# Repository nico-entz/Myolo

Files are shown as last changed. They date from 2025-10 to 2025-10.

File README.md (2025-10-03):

# Myolo

Myolo ist ein Partikel/Myonendetektor auf der Basis von Szintillatoren und Silizium-Photodioden, der ohne SMD-Bauteile aufgebaut werden kann.

Myolo nutzt Koinzidenz, um Myonen von anderen Teilchen zu unterscheiden. Um dies zu realisieren, nutzt er zwei voneinander unabhängige Detektoren. Anhand der zeitlichen Korrelation der Signale beider Detektoren kann auf die Teilchenart geschlossen werden.

Als Szintillatoren kommen Bicron BC408-Plastikszintillatoren der Maße 50x50x10 mm zum Einsatz.

Als SiPMs werden onsemi MICROFC-60035-SMT-TR genutzt. Die Bias-Spannung von 29,5 V wird mittels eines simplen DC-DC-Wandlers erzeugt.

Die für die Operationsverstärkerschaltung notwendige symmetrische Versorgungsspannung von +/- 15V wird ebenfalls durch einen DC-DC-Wandler erzeugt.

Myolo basiert lose auf dem CosmicWatch-Projekt (http://www.cosmicwatch.lns.mit.edu/) und nutzt daher auch dessen SiPM-PCB (https://github.com/spenceraxani/CosmicWatch-Desktop-Muon-Detector-v2/blob/master/PCB_Files/PCB_Gerber_files.zip).

Im Gegensatz zu CosmicWatch nutzt Myolo jedoch einen leistungsfähigen STM32H7-Mikrocontroller, wodurch es möglich wird, beide Detektoren quasi zeitgleich auszulesen.

--------------------------------------

Myolo is a particle/muon detector based on scintillators and silicon photodiodes that can be constructed without SMD components.

Myolo uses the coincidence method to distinguish muons from other particles. To achieve this, it uses two independent detectors. The type of particle can be determined based on the temporal correlation of the signals from both detectors.

Bicron BC408 plastic scintillators measuring 50x50x10 mm are used as scintillators.

Onsemi MICROFC-60035-SMT-TR are used as SiPMs. The bias voltage of 29.5 V is generated by a simple DC-DC converter. 

The symmetrical supply voltage of +/- 15V required for the operational amplifier circuit is also generated by a DC-DC converter.

Myolo is loosely based on the CosmicWatch project (http://www.cosmicwatch.lns.mit.edu/) and therefore also uses its SiPM PCB (https://github.com/spenceraxani/CosmicWatch-Desktop-Muon-Detector-v2/blob/master/PCB_Files/PCB_Gerber_files.zip).

Unlike CosmicWatch, however, Myolo uses a powerful STM32H7 microcontroller, which makes it possible to read out both detectors virtually simultaneously.

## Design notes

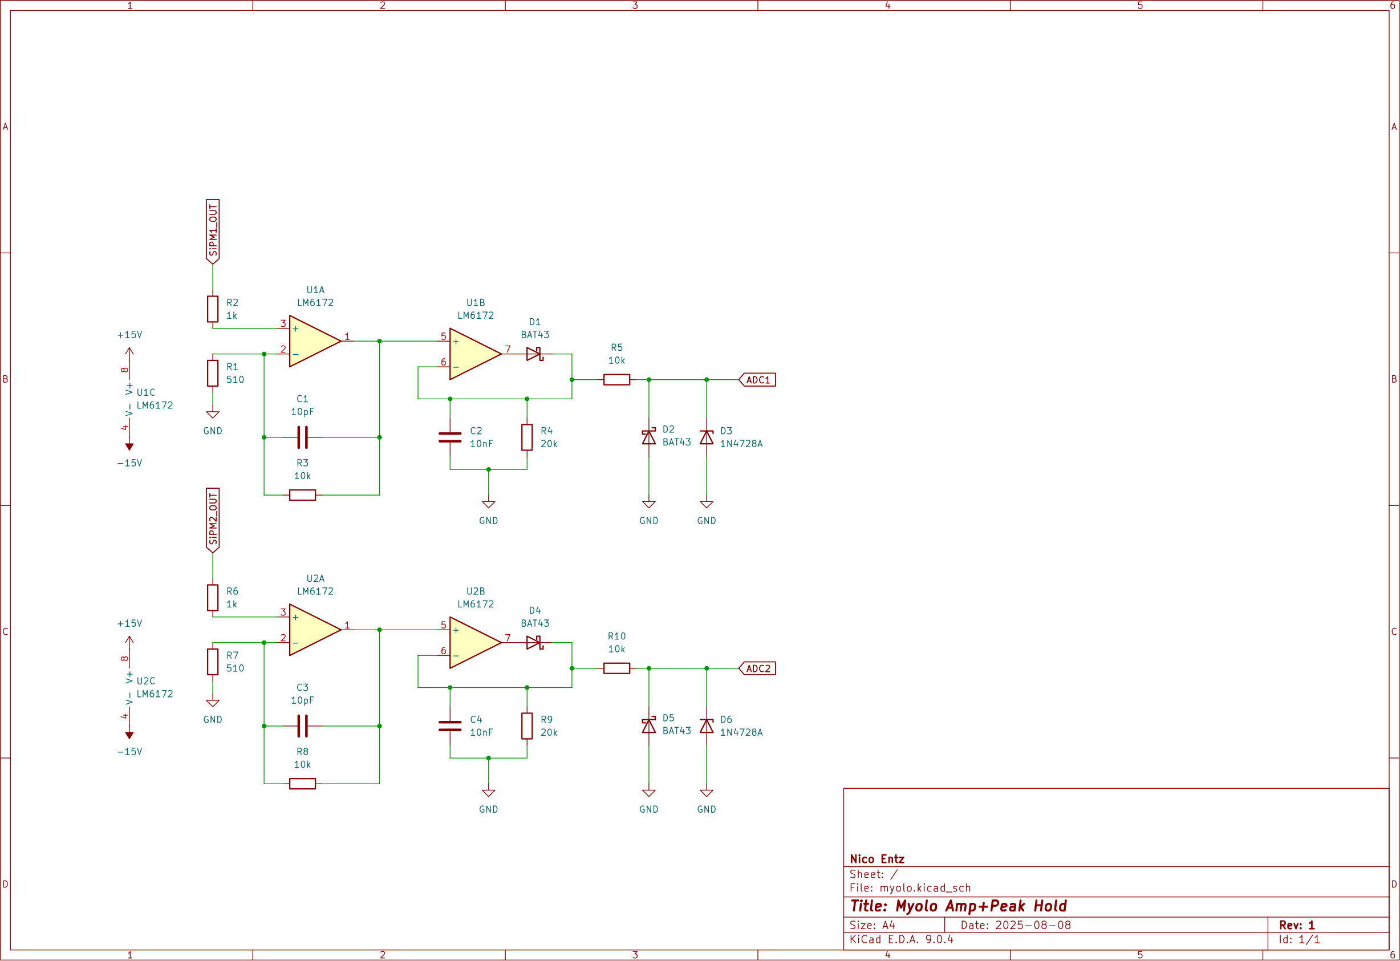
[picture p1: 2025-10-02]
circuit_diagrams/circuit_diagram.png

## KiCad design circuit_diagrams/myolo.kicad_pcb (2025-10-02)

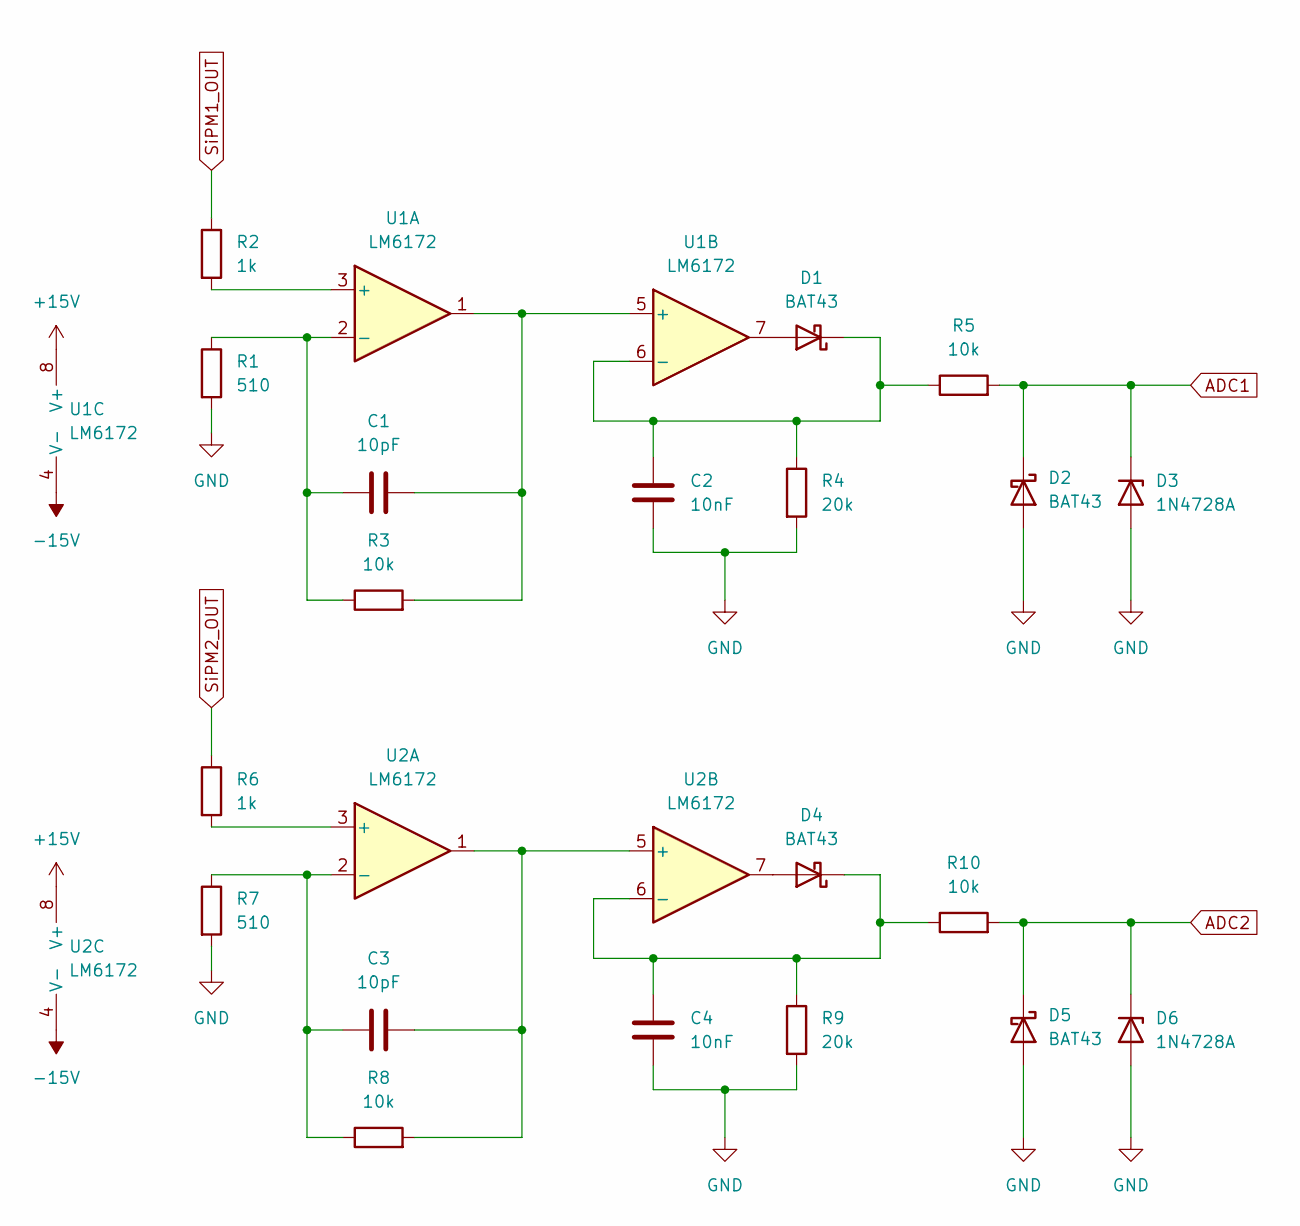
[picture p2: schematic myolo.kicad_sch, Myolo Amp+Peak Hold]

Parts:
C1, C3: 10pF; CP_Radial_D4.0mm_P2.00mm
C2, C4: 10nF; CP_Radial_D4.0mm_P2.00mm
D1, D2, D4, D5: BAT43; D_DO-35_SOD27_P7.62mm_Horizontal
D3, D6: 1N4728A; D_DO-41_SOD81_P10.16mm_Horizontal
R1, R7: 510; R_Axial_DIN0207_L6.3mm_D2.5mm_P15.24mm_Horizontal
R2, R6: 1k; R_Axial_DIN0207_L6.3mm_D2.5mm_P15.24mm_Horizontal
R3, R5, R8, R10: 10k; R_Axial_DIN0207_L6.3mm_D2.5mm_P15.24mm_Horizontal
R4, R9: 20k; R_Axial_DIN0207_L6.3mm_D2.5mm_P15.24mm_Horizontal
U1, U2: LM6172; DIP-8_W10.16mm

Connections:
+15V: U1.8 (V+), U2.8 (V+)
-15V: U1.4 (V-), U2.4 (V-)
ADC1: D2.1 (K), D3.1 (K), R5.2
ADC2: D5.1 (K), D6.1 (K), R10.2
GND: C2.2, C4.2, D2.2 (A), D3.2 (A), D5.2 (A), D6.2 (A), R1.2, R4.2, R7.2, R9.2
unnamed: D1.2 (A), U1.7
unnamed: C2.1, D1.1 (K), R4.1, R5.1, U1.6 (-)
unnamed: D4.2 (A), U2.7
unnamed: C4.1, D4.1 (K), R9.1, R10.1, U2.6 (-)
unnamed: R2.2, U1.3 (+)
unnamed: C1.1, R1.1, R3.1, U1.2 (-)
unnamed: C1.2, R3.2, U1.1, U1.5 (+)
unnamed: R6.2, U2.3 (+)
unnamed: C3.1, R7.1, R8.1, U2.2 (-)
unnamed: C3.2, R8.2, U2.1, U2.5 (+)
SiPM1_OUT: R2.1
SiPM2_OUT: R6.1

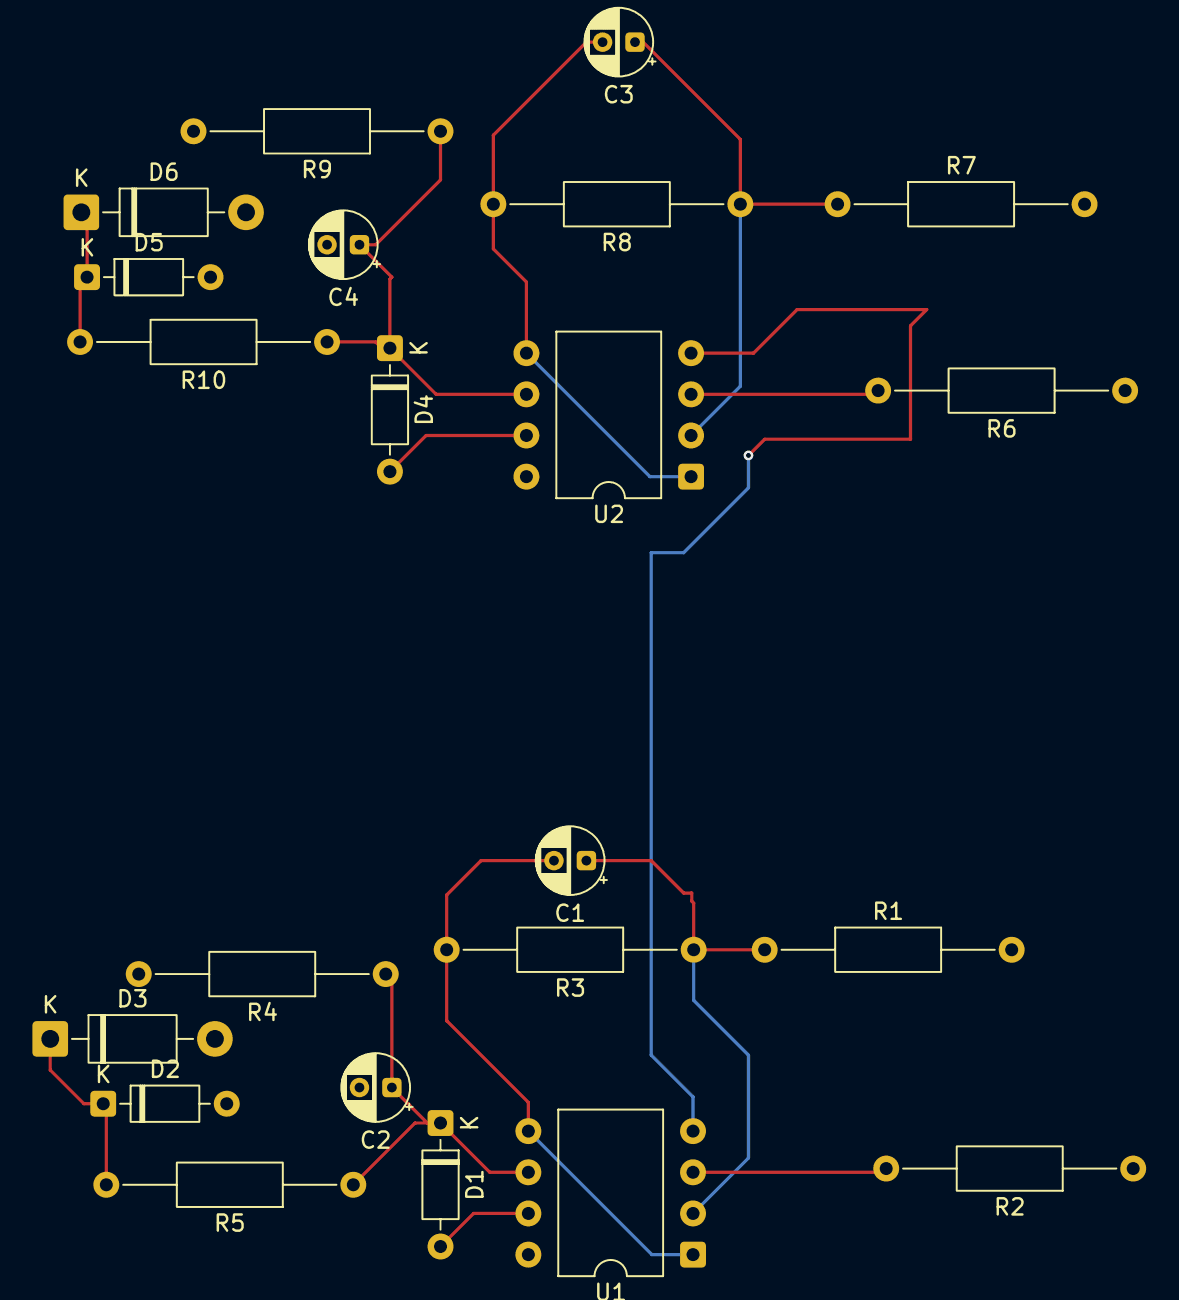
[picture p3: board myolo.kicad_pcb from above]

Board: 2 copper layers, 22 parts (0 on the bottom side), 15 nets.

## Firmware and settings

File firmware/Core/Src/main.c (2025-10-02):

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
/* Includes ------------------------------------------------------------------*/
#include "main.h"
#include "fatfs.h"
#include "usb_device.h"

/* USER CODE BEGIN Includes */
#include <string.h>
#include <st7735.h>
#include "fonts.h"
#include "testimg.h"
#include <math.h>

/* USER CODE END Includes */

ADC_HandleTypeDef hadc1;
ADC_HandleTypeDef hadc2;

SD_HandleTypeDef hsd1;

SPI_HandleTypeDef hspi4;

TIM_HandleTypeDef htim2;

UART_HandleTypeDef huart2;

/* USER CODE BEGIN PV */
long counter = 0;
bool written = false;
volatile long adc_callback_counter = 0;
#define ADCBUFSIZE 1000
uint32_t adcbuf[ADCBUFSIZE];
bool adc_ready = false;

char log_filename[32];
uint32_t file_counter = 0;

/* USER CODE END PV */

void SystemClock_Config(void);
void PeriphCommonClock_Config(void);
static void MPU_Config(void);
static void MX_GPIO_Init(void);
static void MX_SPI4_Init(void);
static void MX_ADC1_Init(void);
static void MX_ADC2_Init(void);
static void MX_TIM2_Init(void);
static void MX_SDMMC1_SD_Init(void);
static void MX_USART2_UART_Init(void);
/**
  * @brief  The application entry point.
  * @retval int
  */
int main(void)
{

  /* MPU Configuration--------------------------------------------------------*/
  MPU_Config();

  /* MCU Configuration--------------------------------------------------------*/

  /* Reset of all peripherals, Initializes the Flash interface and the Systick. */
  HAL_Init();

  /* Configure the system clock */
  SystemClock_Config();

  /* Configure the peripherals common clocks */
  PeriphCommonClock_Config();

  /* Initialize all configured peripherals */
  MX_GPIO_Init();
  MX_SPI4_Init();
  MX_ADC1_Init();
  MX_ADC2_Init();
  MX_TIM2_Init();
  MX_USB_DEVICE_Init();
  MX_SDMMC1_SD_Init();
  MX_FATFS_Init();
  MX_USART2_UART_Init();
  /* USER CODE BEGIN 2 */

  // init display
  ST7735_Init();

  // clear display
  ST7735_FillScreen(0x0000);

  // adc calibration
  HAL_ADCEx_Calibration_Start(&hadc1, ADC_SINGLE_ENDED, DISABLE);
  HAL_ADCEx_Calibration_Start(&hadc2, ADC_SINGLE_ENDED, DISABLE);

  // start timer
  HAL_TIM_Base_Start_IT(&htim2);
  /* USER CODE END 2 */

  /* Infinite loop */
  /* USER CODE BEGIN WHILE */

  // definitions for upper and lower threshold
  // (detector is triggered if ADC value hits upper threshold)
  // (all values are buffered until ADC value hits lower threshold)
  // (then the mean value of these values is calculated)
  uint16_t upper_thresh = 400;
  uint16_t lower_thresh = 300;

  // define allowed coincidence time difference
  uint16_t coincidence_window = 100;

  bool triggered = false;
  bool triggered2 = false;

  uint32_t sumval = 0;
  uint32_t conv_cnt = 0;
  uint16_t res_val = 0;

  uint32_t sumval2 = 0;
  uint32_t conv_cnt2 = 0;
  uint16_t res_val2 = 0;

  uint32_t c1_evt_cnt = 0;
  uint32_t c2_evt_cnt = 0;
  uint32_t coinc_evt_cnt = 0;

  uint32_t times1[100];
  uint8_t counter1 = 0;
  float rate1 = 0;

  uint32_t times2[100];
  uint8_t counter2 = 0;
  float rate2 = 0;

  uint32_t coinc_times[20];
  uint8_t coinc_count = 0;
  float coinc_rate = 0;

  uint32_t last_count1 = 0;
  uint32_t last_count2 = 0;

  // show status on display
  ST7735_WriteString(0, 10, "No events.", Font_7x10, 0xFFFF, 0x0000);
  ST7735_WriteString(0, 30, "No events.", Font_7x10, 0xFFFF, 0x0000);

  float vref = 3.3f; // reference voltage

  uint32_t microsecs = __HAL_TIM_GET_COUNTER(&htim2);
  uint32_t microsecs2 = __HAL_TIM_GET_COUNTER(&htim2);

  // find lowest numbered unused log file
  findNewFilename();

  // main loop
  while (1)
  {
          // ADC readout
	      char buf[40];
	      HAL_ADC_Start(&hadc1);
	      HAL_ADC_Start(&hadc2);
	      HAL_ADC_PollForConversion(&hadc1, 1);
	      HAL_ADC_PollForConversion(&hadc2, 1);
	      uint16_t val = HAL_ADC_GetValue(&hadc1);
	      uint16_t val2 = HAL_ADC_GetValue(&hadc2);

	      // process data from 1st ADC
	      if (val >= upper_thresh) {
	    	  triggered = true;
	    	  sumval = sumval + val;
	    	  conv_cnt++;
	    	  microsecs = __HAL_TIM_GET_COUNTER(&htim2);
	      } else if ((val < lower_thresh) && (triggered)) {
	    	  res_val = (uint16_t)round(sumval/conv_cnt);

	    	  float voltage = (res_val / 4095.0f) * vref;
	     	  sprintf(buf, "%lu | %.3f V   ", microsecs, voltage);
	          ST7735_WriteString(0, 10, buf, Font_7x10, 0xFFFF, 0x0000);

	          times1[counter1] = microsecs;
	          counter1++;

	          last_count1 = microsecs;
	          if (counter1 == 100) {
	        	  uint32_t timediff = times1[99]-times1[0];
	        	  float timediff_in_min = timediff / 60000000.0f;
	        	  rate1 = 100/timediff_in_min;

	        	  char buf[20];
	        	  sprintf(buf, "%.1f", rate1);
	        	  ST7735_WriteString(0, 70, buf, Font_7x10, 0xFFFF, 0x0000);

	        	  counter1 = 0;
	          }

	          char usbbuf[20];
	          uint8_t buflen = sprintf(usbbuf, "0,%lu,%.3f\n", microsecs, voltage);
	          logToSD(usbbuf, buflen);
	          CDC_Transmit_FS((uint8_t*)usbbuf, buflen);

	          c1_evt_cnt++;

	          if ((c1_evt_cnt % 100) == 0) {
	        	  findNewFilename();
	          }

	    	  sumval = 0;
	    	  conv_cnt = 0;
	     	  triggered = false;

		      sprintf(buf, "%lu", c1_evt_cnt);
		      ST7735_WriteString(0, 50, buf, Font_7x10, 0xFFFF, 0x0000);
	      }

	      // process data from 2nd ADC
	      if (val2 >= upper_thresh) {
	    	  triggered2 = true;
	      	  sumval2 = sumval2 + val2;
	      	  conv_cnt2++;
	    	  microsecs2 = __HAL_TIM_GET_COUNTER(&htim2);
	      } else if ((val2 < lower_thresh) && (triggered2)) {
	    	  res_val2 = (uint16_t)round(sumval2/conv_cnt2);

	    	  float voltage2 = (res_val2 / 4095.0f) * vref;
	     	  sprintf(buf, "%lu | %.3f V   ", microsecs2, voltage2);
	          ST7735_WriteString(0, 30, buf, Font_7x10, 0xFFFF, 0x0000);

	          times2[counter2] = microsecs2;
	          counter2++;

	          last_count2 = microsecs2;

	          if (counter2 == 100) {
	        	  uint32_t timediff = times2[99]-times2[0];
	          	  float timediff_in_min = timediff / 60000000.0f;
	          	  rate2 = 100/timediff_in_min;

	          	  char buf[20];
	          	  sprintf(buf, "%.1f", rate2);
	          	  ST7735_WriteString(60, 70, buf, Font_7x10, 0xFFFF, 0x0000);

	          	  counter2 = 0;
	          }

	          char usbbuf[20];
	          uint8_t buflen = sprintf(usbbuf, "1,%lu,%.3f\n", microsecs2, voltage2);
	          logToSD(usbbuf, buflen);
	          CDC_Transmit_FS((uint8_t*)usbbuf, buflen);

	          c2_evt_cnt++;
	    	  sumval2 = 0;
	    	  conv_cnt2 = 0;
	     	  triggered2 = false;

	     	  sprintf(buf, "%lu", c2_evt_cnt);
		      ST7735_WriteString(60, 50, buf, Font_7x10, 0xFFFF, 0x0000);
	      }


	      if ((last_count1 > 0) && (last_count2 > 0)) {
	    	  if (abs(last_count1-last_count2) < coincidence_window) {
	    		  coinc_evt_cnt++;

	    		  coinc_times[coinc_count] = last_count1;
				  coinc_count++;

	    		  sprintf(buf, "%lu", coinc_evt_cnt);
	    		  ST7735_WriteString(120, 50, buf, Font_7x10, 0xF800, 0x0000);

	    		  last_count1 = 0;
	    		  last_count2 = 0;
	    	  }

	    	  if (coinc_count == 20) {
	    		  uint32_t timediff = coinc_times[19]-coinc_times[0];
	    		  float timediff_in_min = timediff / 60000000.0f;
	    		  coinc_rate = 20/timediff_in_min;

	    		  char buf[20];
	    		  sprintf(buf, "%.1f", coinc_rate);
	    		  ST7735_WriteString(120, 70, buf, Font_7x10, 0xFFFF, 0x0000);

	    		  coinc_count = 0;
	    	  }
	      }
    /* USER CODE END WHILE */

    /* USER CODE BEGIN 3 */
  }
  /* USER CODE END 3 */
}

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
/* USER CODE BEGIN 4 */
uint32_t micros(void)
{
    return __HAL_TIM_GET_COUNTER(&htim2);
}

void HAL_TIM_PeriodElapsedCallback(TIM_HandleTypeDef *htim)
{
	/*
    if(htim->Instance == TIM2)
    {
        HAL_GPIO_TogglePin(GPIOE, GPIO_PIN_3);
    }
    */
}

void logToSD(char* data, uint8_t datalen) {
    char TxBuffer[250];
    FATFS FatFs;
    FIL Fil;
    FRESULT FR_Status;
    UINT WWC; // Write Word Counter
    uint8_t buflen;

    // SD Karte mounten
    FR_Status = f_mount(&FatFs, SDPath, 1);
    if (FR_Status == FR_OK)
    {
        // Datei zum Anhängen öffnen (erstellt, falls nicht vorhanden)
        FR_Status = f_open(&Fil, log_filename, FA_WRITE | FA_OPEN_ALWAYS);
        if(FR_Status == FR_OK) {
            // Cursor ans Ende der Datei setzen
            f_lseek(&Fil, f_size(&Fil));
            // Daten schreiben
            f_write(&Fil, data, datalen, &WWC);
            // Datei schließen
            f_close(&Fil);
            buflen = sprintf(TxBuffer, "Data written to SD\r\n");
            CDC_Transmit_FS((uint8_t*)TxBuffer, buflen);
        } else {
            buflen = sprintf(TxBuffer, "Error! Opening log.txt failed, Error Code: (%i)\r\n", FR_Status);
            CDC_Transmit_FS((uint8_t*)TxBuffer, buflen);
        }
    } else {
        buflen = sprintf(TxBuffer, "Error! Mounting SD card failed, Error Code: (%i)\r\n", FR_Status);
        CDC_Transmit_FS((uint8_t*)TxBuffer, buflen);
    }
}

int fileExists(char* filename) {
	FATFS FatFs;
	FRESULT FR_Status;

	// mount sd card
	FR_Status = f_mount(&FatFs, SDPath, 1);
	if (FR_Status == FR_OK) {
		FILINFO fno;
		FRESULT res;

		res = f_stat(filename, &fno);
		if (res == FR_OK) {
			return 1;
		} else if (res == FR_NO_FILE) {
			return 0;
		} else {
			return 2;
		}
	}
	return 0;
}

void findNewFilename() {
	sprintf(log_filename, "log_%lu.txt", file_counter);
	while ((fileExists(log_filename) == 1) && (file_counter < 100000)) {
		file_counter++;
		sprintf(log_filename, "log_%lu.txt", file_counter);
	}

	char usbbuf[40];
	uint8_t buflen = sprintf(usbbuf, "%s\n", log_filename);
    CDC_Transmit_FS((uint8_t*)usbbuf, buflen);
}

void SDIO_SDCard_Test(void)
{
  char TxBuffer[250];
  FATFS FatFs;
  FIL Fil;
  FRESULT FR_Status;
  FATFS *FS_Ptr;
  UINT RWC, WWC; // Read/Write Word Counter
  DWORD FreeClusters;
  uint32_t TotalSize, FreeSpace;
  char RW_Buffer[200];
  uint8_t buflen;
  do
  {
    //------------------[ Mount The SD Card ]--------------------
    FR_Status = f_mount(&FatFs, SDPath, 1);
    if (FR_Status != FR_OK)
    {
      buflen = sprintf(TxBuffer, "Error! While Mounting SD Card, Error Code: (%i)\r\n", FR_Status);
      CDC_Transmit_FS((uint8_t*)TxBuffer, buflen);
      break;
    }
    buflen = sprintf(TxBuffer, "SD Card Mounted Successfully! \r\n\n");
    CDC_Transmit_FS((uint8_t*)TxBuffer, buflen);
    //------------------[ Get & Print The SD Card Size & Free Space ]--------------------
    f_getfree("", &FreeClusters, &FS_Ptr);
    TotalSize = (uint32_t)((FS_Ptr->n_fatent - 2) * FS_Ptr->csize * 0.5);
    FreeSpace = (uint32_t)(FreeClusters * FS_Ptr->csize * 0.5);
    buflen = sprintf(TxBuffer, "Total SD Card Size: %lu Bytes\r\n", TotalSize);
    CDC_Transmit_FS((uint8_t*)TxBuffer, buflen);
    buflen = sprintf(TxBuffer, "Free SD Card Space: %lu Bytes\r\n\n", FreeSpace);
    CDC_Transmit_FS((uint8_t*)TxBuffer, buflen);
    //------------------[ Open A Text File For Write & Write Data ]--------------------
    //Open the file
    FR_Status = f_open(&Fil, "MyTextFile.txt", FA_WRITE | FA_READ | FA_CREATE_ALWAYS);
    if(FR_Status != FR_OK)
    {
      buflen = sprintf(TxBuffer, "Error! While Creating/Opening A New Text File, Error Code: (%i)\r\n", FR_Status);
      CDC_Transmit_FS((uint8_t*)TxBuffer, buflen);
      break;
    }
    buflen = sprintf(TxBuffer, "Text File Created & Opened! Writing Data To The Text File..\r\n\n");
    CDC_Transmit_FS((uint8_t*)TxBuffer, buflen);
    // (1) Write Data To The Text File [ Using f_puts() Function ]
    f_puts("Hello! From STM32 To SD Card Over SDMMC, Using f_puts()\n", &Fil);
    // (2) Write Data To The Text File [ Using f_write() Function ]
    strcpy(RW_Buffer, "Hello! From STM32 To SD Card Over SDMMC, Using f_write()\r\n");
    f_write(&Fil, RW_Buffer, strlen(RW_Buffer), &WWC);
    // Close The File
    f_close(&Fil);
    //------------------[ Open A Text File For Read & Read Its Data ]--------------------
    // Open The File
    FR_Status = f_open(&Fil, "MyTextFile.txt", FA_READ);
    if(FR_Status != FR_OK)
    {
      buflen = sprintf(TxBuffer, "Error! While Opening (MyTextFile.txt) File For Read.. \r\n");
      CDC_Transmit_FS((uint8_t*)TxBuffer, buflen);
      break;
    }
    // (1) Read The Text File's Data [ Using f_gets() Function ]
    f_gets(RW_Buffer, sizeof(RW_Buffer), &Fil);
    buflen = sprintf(TxBuffer, "Data Read From (MyTextFile.txt) Using f_gets():%s", RW_Buffer);
    CDC_Transmit_FS((uint8_t*)TxBuffer, buflen);
    // (2) Read The Text File's Data [ Using f_read() Function ]
    f_read(&Fil, RW_Buffer, f_size(&Fil), &RWC);
    buflen = sprintf(TxBuffer, "Data Read From (MyTextFile.txt) Using f_read():%s", RW_Buffer);
    CDC_Transmit_FS((uint8_t*)TxBuffer, buflen);
    // Close The File
    f_close(&Fil);
    buflen = sprintf(TxBuffer, "File Closed! \r\n\n");
    CDC_Transmit_FS((uint8_t*)TxBuffer, buflen);
    //------------------[ Open An Existing Text File, Update Its Content, Read It Back ]--------------------
    // (1) Open The Existing File For Write (Update)
    FR_Status = f_open(&Fil, "MyTextFile.txt", FA_OPEN_EXISTING | FA_WRITE);
    FR_Status = f_lseek(&Fil, f_size(&Fil)); // Move The File Pointer To The EOF (End-Of-File)
    if(FR_Status != FR_OK)
    {
      buflen = sprintf(TxBuffer, "Error! While Opening (MyTextFile.txt) File For Update.. \r\n");
      CDC_Transmit_FS((uint8_t*)TxBuffer, buflen);
      break;
    }
    // (2) Write New Line of Text Data To The File
    FR_Status = f_puts("This New Line Was Added During File Update!\r\n", &Fil);
    f_close(&Fil);
    memset(RW_Buffer,'\0',sizeof(RW_Buffer)); // Clear The Buffer
    // (3) Read The Contents of The Text File After The Update
    FR_Status = f_open(&Fil, "MyTextFile.txt", FA_READ); // Open The File For Read
    f_read(&Fil, RW_Buffer, f_size(&Fil), &RWC);
    buflen = sprintf(TxBuffer, "Data Read From (MyTextFile.txt) After Update:\r\n%s", RW_Buffer);
    CDC_Transmit_FS((uint8_t*)TxBuffer, buflen);
    f_close(&Fil);
    //------------------[ Delete The Text File ]--------------------
    // Delete The File
    /*
    FR_Status = f_unlink(MyTextFile.txt);
    if (FR_Status != FR_OK){
        sprintf(TxBuffer, "Error! While Deleting The (MyTextFile.txt) File.. \r\n");
        USC_CDC_Print(TxBuffer);
    }
    */
  } while(0);
  //------------------[ Test Complete! Unmount The SD Card ]--------------------
  FR_Status = f_mount(NULL, "", 0);
  if (FR_Status != FR_OK)
  {
	  buflen = sprintf(TxBuffer, "\r\nError! While Un-mounting SD Card, Error Code: (%i)\r\n", FR_Status);
      CDC_Transmit_FS((uint8_t*)TxBuffer, buflen);
  } else{
	  buflen = sprintf(TxBuffer, "\r\nSD Card Un-mounted Successfully! \r\n");
      CDC_Transmit_FS((uint8_t*)TxBuffer, buflen);
  }
}
/* USER CODE END 4 */

 /* MPU Configuration */

void MPU_Config(void)
{
  MPU_Region_InitTypeDef MPU_InitStruct = {0};

  /* Disables the MPU */
  HAL_MPU_Disable();

  /** Initializes and configures the Region and the memory to be protected
  */
  MPU_InitStruct.Enable = MPU_REGION_ENABLE;
  MPU_InitStruct.Number = MPU_REGION_NUMBER0;
  MPU_InitStruct.BaseAddress = 0x0;
  MPU_InitStruct.Size = MPU_REGION_SIZE_4GB;
  MPU_InitStruct.SubRegionDisable = 0x87;
  MPU_InitStruct.TypeExtField = MPU_TEX_LEVEL0;
  MPU_InitStruct.AccessPermission = MPU_REGION_NO_ACCESS;
  MPU_InitStruct.DisableExec = MPU_INSTRUCTION_ACCESS_DISABLE;
  MPU_InitStruct.IsShareable = MPU_ACCESS_SHAREABLE;
  MPU_InitStruct.IsCacheable = MPU_ACCESS_NOT_CACHEABLE;
  MPU_InitStruct.IsBufferable = MPU_ACCESS_NOT_BUFFERABLE;

  HAL_MPU_ConfigRegion(&MPU_InitStruct);
  /* Enables the MPU */
  HAL_MPU_Enable(MPU_PRIVILEGED_DEFAULT);

}

/**
  * @brief  This function is executed in case of error occurrence.
  * @retval None
  */
void Error_Handler(void)
{
  /* USER CODE BEGIN Error_Handler_Debug */
  /* User can add his own implementation to report the HAL error return state */
  __disable_irq();
  while (1)
  {
  }
  /* USER CODE END Error_Handler_Debug */
}
#ifdef USE_FULL_ASSERT
/**
  * @brief  Reports the name of the source file and the source line number
  *         where the assert_param error has occurred.
  * @param  file: pointer to the source file name
  * @param  line: assert_param error line source number
  * @retval None
  */
void assert_failed(uint8_t *file, uint32_t line)
{
  /* USER CODE BEGIN 6 */
  /* User can add his own implementation to report the file name and line number,
     ex: printf("Wrong parameters value: file %s on line %d\r\n", file, line) */
  /* USER CODE END 6 */
}
#endif /* USE_FULL_ASSERT */

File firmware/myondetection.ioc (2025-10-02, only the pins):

Mcu.UserName=STM32H750VBTx
PA1.Signal=GPIO_Input
PA11.Signal=USB_OTG_FS_DM
PA12.Signal=USB_OTG_FS_DP
PA4.Signal=ADCx_INP18
PA6.Signal=ADCx_INP3
PC10.Signal=SDMMC1_D2
PC11.Signal=SDMMC1_D3
PC12.Signal=SDMMC1_CK
PC8.Signal=SDMMC1_D0
PC9.Signal=SDMMC1_D1
PD2.Signal=SDMMC1_CMD
PD5.Signal=USART2_TX
PE10.GPIO_Label=LCD_LED
PE10.Signal=GPIO_Output
PE11.GPIO_Label=LCD_CS
PE11.Signal=GPIO_Output
PE12.Signal=SPI4_SCK
PE13.GPIO_Label=LCD_WR_RS
PE13.Signal=GPIO_Output
PE14.Signal=SPI4_MOSI
PE15.Signal=GPIO_Output
PE3.Signal=GPIO_Output

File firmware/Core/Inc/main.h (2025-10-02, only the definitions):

#define LCD_LED_Pin GPIO_PIN_10
#define LCD_LED_GPIO_Port GPIOE
#define LCD_CS_Pin GPIO_PIN_11
#define LCD_CS_GPIO_Port GPIOE
#define LCD_WR_RS_Pin GPIO_PIN_13
#define LCD_WR_RS_GPIO_Port GPIOE

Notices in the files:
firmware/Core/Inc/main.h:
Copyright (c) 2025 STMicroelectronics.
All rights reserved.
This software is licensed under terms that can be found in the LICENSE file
